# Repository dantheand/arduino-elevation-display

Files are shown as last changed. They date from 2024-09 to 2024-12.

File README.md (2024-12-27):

# Altimeter / Elevation Display for Car

This will display your current elevation/altitude based off of a GPS fix. It also dims the display after sunset. 

For elevations above 9,999 feet, the display reads out using a shortened syntax. For example 10,500 feet will read out as "10.5k".

installed_altimeter

## Requirements

### Parts:
* [Adafruit Arduino Metro Mini w/ STEMMA QT](https://www.adafruit.com/product/2590)
* [Adafruit Mini GPS w/ STEMMA QT](https://www.adafruit.com/product/4415)
* [Adafruit 7 Segment Display w/ STEMMA QT](https://www.adafruit.com/product/878)
* [1x short (50mm) STEMMA QT cable](https://www.adafruit.com/product/4399)
* [1x long (400mm) STEMMA QT cable](https://www.adafruit.com/product/5385)
* [12v to USB univeral power adapter tap](https://www.amazon.com/dp/B0D4LGW3JM) (for powering the Arduino off of my rear-view mirror wiring harness)

### Tools:
* Soldering iron (for final assembly of the 7-segment display)
* Multimeter (for finding positive and negative wires in the rear-view mirror wiring harness)
    * Note: this may not be needed if you can find a rear-view mirror adapter specific to your car rather than using the universal adapter I listed above.

### Software:
* [Arduino IDE](https://docs.arduino.cc/software/ide/#ide-v2) (for compiling and uploading the code to the Arduino)

## Instructions

### Hardware assembly
The 7-segment display I used required some simple soldering to get the final assembled part. Instructions can be found on the Adafruit website.

Thanks to the STEMMA QT ports, connecting the components is a breeze! I simply wired it like:

```
Arduino <--short cable--> GPS <------long cable------> Display
```

Having a long cable go to the display made it so I could stuff the rest of the components out of sight while keeping flexibility in where I placed the display.

### Software
* Install Arduino IDE and the appropriate libraries
* Upload the `.ino` sketch included in this repository to the Arduino using the Arduino IDE & a USB cable

**NOTE:** I needed to make a minor modification to the `Sunrise` v2.0.4 library to get compiler to work (I added `#define rint(x) (double)lrint(x)` as suggested [here](https://github.com/signetica/SunRise/blob/93c2db79c580f0758d3f497aed1d599d7d815036/SunRise.cpp#L263)). 
This required editing the library file locally. 

### 3D Printing the Case
Create the case by printing the two .stl files in this repo (units are in millimeter). The case snaps together and can be separated by prying the small notch on the side.

#### Printer settings
- Printer make: Prusa
- Printer: i3 MK2S
- Rafts: No
- Supports: No
- Resolution: 0.2mm
- Infill: 20%

### Car installation
The Arduino runs off of USB power, which I got via a 12V-to-USB adapter tapped into the 12V source that powers my rear-view mirror. 
These adapters are usually used to power dashcams. 
You may be able to find a rear-view mirror adapter specific to your car which would allow you to skip the multimeter work.

If you do not have a powered rear-view mirror, you will have to power a USB adapter another way.

#### Access the rear-view mirror power harness 
You may need to remove some trim to do this.

#### Identify the positive and negative wires using a multimeter
First make sure your car is in a state that is actually providing power to the rear-view mirror (e.g. ignition turned on). Then, with your multimeter in voltage mode, probe the outputs until you see a signal around 12V. Protip: if you see black and red wires start by testing those. 

You may need to insert some wires into harness to be able to probe the outputs like I did below:

testing_leads

#### Tap the 12V power
The universal adapter I used requires you to insert its leads *into the back* of the wiring harness like so:

installed_tap

#### Install the hardware
On my car there was a small compartment above the rear-view mirror where I could stuff the Arduino and GPS components without having to take apart any trim. I simply put all the components in there and fed a single wire out to the display which was mounted via velcro.

That's it!

## Other Learning Resources
I highly recommend checking out the guides in the [Adafruit Learning System](https://learn.adafruit.com/) if you want to learn more about any of the parts or their Arduino libraries. 

Each Arduino library also comes with loads of useful examples you can find in the Arduino IDE via: `File > Examples`

## Acknowledgements
The Arduino code and car installation instructions were adapted from Kris Linquist's [Arduino-Elevation-Display](https://github.com/klinquist/Arduino-Elevation-Display) repo.

With the help of Devin J., the 3D model for the 7-segment display case was adapted from [Pyrce007's Adafruit Segmented Display Case](https://www.thingiverse.com/thing:2669204). We added the STEMMA QT ports and adjusted the dimensions of the face opening. 

## Licenses
The Arduino code license is MIT.

The display case .stl file is licensed under the [Creative Commons - Attribution - Share Alike](https://creativecommons.org/licenses/by-sa/3.0/) license to be compatible with the license on the [original source](https://www.thingiverse.com/thing:2669204).

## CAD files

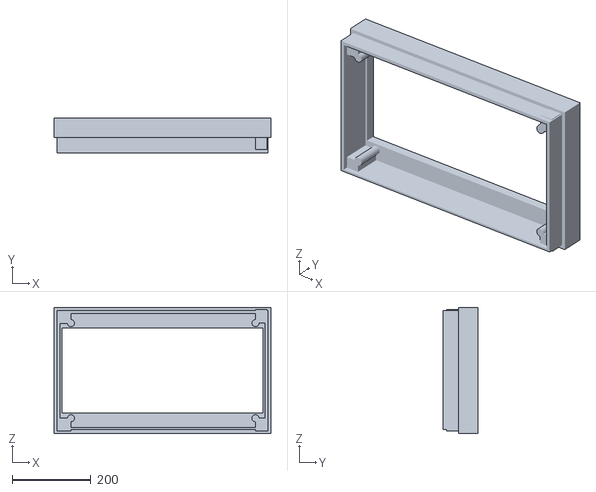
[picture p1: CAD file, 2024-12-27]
altimeter_case_face_plate.stl
550.0 x 90.0 x 320.0

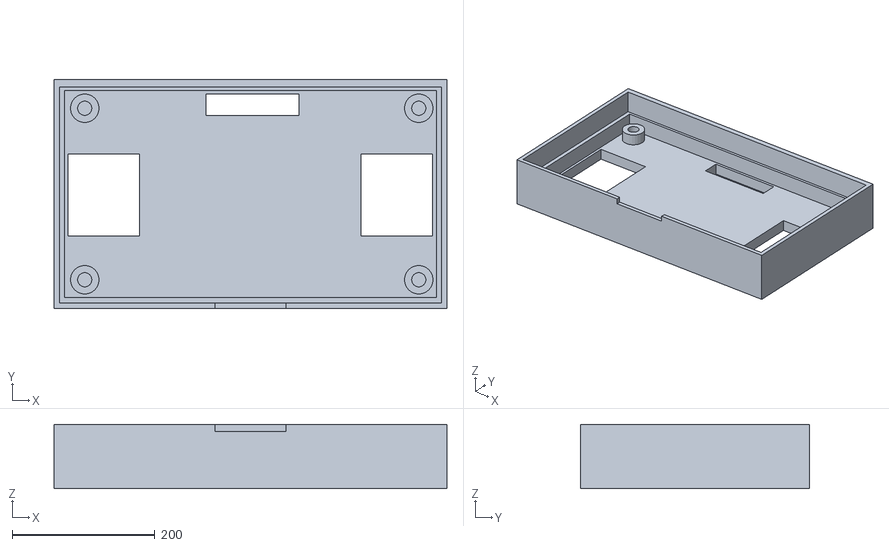
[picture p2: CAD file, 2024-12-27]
altimeter_case_back_plate.stl
550.0 x 320.0 x 90.0

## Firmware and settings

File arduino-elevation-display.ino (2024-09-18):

// Elevation display by Dan Anderson
// Forked from https://github.com/klinquist/Arduino-Elevation-Display by Kris Linquist

// Tested and works great with the Adafruit Mini GPS PA1010D Breakout board
// using MTK3333 chipset
//    ------> https://www.adafruit.com/product/4415

//And the Adafruit 7 segment I2C LCD

#include <Wire.h>
#include <SoftwareSerial.h>

// v1.6.1
#include <TimeLib.h>
// Mild modification required for Sunrise v2.0.4 to get it to compile with Arduino UNO (see README)
#include <SunRise.h>
// v1.5.1
#include "Adafruit_LEDBackpack.h"
// v1.7.5
#include <Adafruit_GPS.h>

Adafruit_7segment matrix = Adafruit_7segment();

SunRise sr;

tmElements_t te;  //Time elements structure
time_t unixTime; // a time stamp


int daytimeBrightness = 10;
int nighttimeBrightness = 0;
int currentBrightness;

// Connect to the GPS on the hardware I2C port (STEMMA QT)
Adafruit_GPS GPS(&Wire);

// Set GPSECHO to 'false' to turn off echoing the GPS data to the Serial console
// Set to 'true' if you want to debug and listen to the raw GPS sentences
#define GPSECHO  false

// Set brightness based on if it's daytime or nighttime
void setBrightness()
{
  te.Second = GPS.seconds;
  te.Hour = GPS.hour;
  te.Minute = GPS.minute;
  te.Day = GPS.day;
  te.Month = GPS.month;
  int actualYear = 2000 + GPS.year;
  te.Year = actualYear - 1970;
  unixTime = makeTime(te);

  float lata = GPS.latitude/100;
  float longi = 0 - (GPS.longitude/100);

  sr.calculate(lata, longi, unixTime);
  Serial.print("Unixtime: ");
  Serial.println(unixTime);

  if (sr.isVisible){
    Serial.println("It's daytime!");
    if (currentBrightness != daytimeBrightness) {
      Serial.println("Setting brightness to day");
      matrix.setBrightness(daytimeBrightness);
      currentBrightness = daytimeBrightness;
    }
  } else {
    Serial.println("It's nighttime!");
    if (currentBrightness != nighttimeBrightness) {
      Serial.println("Setting brightness to night");
      matrix.setBrightness(nighttimeBrightness);
      currentBrightness = nighttimeBrightness;
    }   
  }
}

void setup()
{

  // Print out to serial port at 115200 so we can read the GPS fast enough and echo without dropping chars
  Serial.begin(115200);

  // Default I2C address for display is 0x70
  matrix.begin(0x70);
  matrix.clear();

  Wire.setClock(100000);

  // Just show dashes until we get a GPS fix
  matrix.print("----");
  matrix.writeDisplay();

  Serial.print("Startup: setting brightness to: ");
  Serial.println(nighttimeBrightness);
  matrix.setBrightness(nighttimeBrightness);
  currentBrightness = nighttimeBrightness;
  delay(5000);
 

  // 9600 NMEA is the default baud rate for Adafruit MTK GPS's- some use 4800
  // The I2C address to use is 0x10
  GPS.begin(0x10);  

  // uncomment this line to turn on RMC (recommended minimum) and GGA (fix data) including altitude
  GPS.sendCommand(PMTK_SET_NMEA_OUTPUT_RMCGGA);
  // uncomment this line to turn on only the "minimum recommended" data
  //GPS.sendCommand(PMTK_SET_NMEA_OUTPUT_RMCONLY);
  // For parsing data, we don't suggest using anything but either RMC only or RMC+GGA since
  // the parser doesn't care about other sentences at this time

  // Set the update rate
  GPS.sendCommand(PMTK_SET_NMEA_UPDATE_1HZ);   // 1 Hz update rate
  // For the parsing code to work nicely and have time to sort thru the data, and
  // print it out we don't suggest using anything higher than 1 Hz

  // Request updates on antenna status, comment out to keep quiet
  GPS.sendCommand(PGCMD_ANTENNA);

  delay(1000);
  // Ask for firmware version
  GPS.println(PMTK_Q_RELEASE);
  
}

uint32_t timer = millis();
void loop()                     // run over and over again
{
  char c = GPS.read();
  // if you want to debug, this is a good time to do it!
  if ((c) && (GPSECHO))
    Serial.write(c);

  // if a sentence is received, we can check the checksum, parse it...
  if (GPS.newNMEAreceived()) {
    // a tricky thing here is if we print the NMEA sentence, or data
    // we end up not listening and catching other sentences!
    // so be very wary if using OUTPUT_ALLDATA and trytng to print out data
    //Serial.println(GPS.lastNMEA());   // this also sets the newNMEAreceived() flag to false

    if (!GPS.parse(GPS.lastNMEA()))   // this also sets the newNMEAreceived() flag to false
      return;  // we can fail to parse a sentence in which case we should just wait for another
  }

  // approximately every 2 seconds or so, update the display
  if (millis() - timer > 2000) {
    timer = millis(); // reset the timer

    Serial.print("Fix: "); Serial.print((int)GPS.fix);
    Serial.print(" quality: "); Serial.println((int)GPS.fixquality);
    if (GPS.fix) {

      setBrightness();

      // Calculate and display altitude
      double doubFt = GPS.altitude * 3.28084;
      // Round to nearest 10
      int mod = (int) doubFt % 10;
      if (mod < 5) {
      doubFt = doubFt - mod;
      } else {
        doubFt = doubFt + (10 - mod);
      }
      int intAltitude = (int)doubFt;

      // If it's greater than 9,999, display in the thousands instead (e.g. 11300 will be 11.3K)
      if (intAltitude > 9999){
        matrix.writeDigitNum(0, (intAltitude / 10000U) % 10);
        matrix.writeDigitNum(1, (intAltitude / 1000U) % 10, true);
        matrix.writeDigitNum(3, (intAltitude / 100U) % 10);
        // This is the ASCII code for the letter "K"
        matrix.writeDigitAscii(4, 75);
      } else {
        matrix.print(intAltitude);
      }
      matrix.writeDisplay(); 

      Serial.print("Altitude: "); Serial.println(intAltitude);
      Serial.print("Satellites: "); Serial.println((int)GPS.satellites);
    } 
  }
}

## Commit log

2024-09-08 swapped out 7 segment library
    [arduino-elevation-display.ino]
2024-09-18 Update arduino-elevation-display.ino
    adding versions
2024-12-27 Adding .stl files for case
    [altimeter_case_back_plate.stl, altimeter_case_face_plate.stl]
